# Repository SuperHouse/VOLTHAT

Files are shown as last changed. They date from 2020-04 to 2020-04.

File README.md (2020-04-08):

Voltage Regulator Hat for Raspberry Pi
=======================================
Designed by Nick Fryer and Jonathan Oxer

FEATURES
--------

Supply power via screw terminals, 2.1mm DC jack, or the PoE header on
Raspberry Pi 3 B+. Regulates down to 5V to supply the Raspberry Pi.

 * I2C header for OLED.
 * I2C-BREAKOUT header.
 * Prototyping area.

INSTALLATION
------------
The design is saved as an EAGLE project. EAGLE PCB design software is
available from www.cadsoftusa.com free for non-commercial use. To use
this project download it and place the directory containing these files
into the "eagle" directory on your computer. Then open EAGLE and
navigate to the project.

DISTRIBUTION
------------
The specific terms of distribution of this project are governed by the
license referenced below.

LICENSE
-------
Licensed under the TAPR Open Hardware License (www.tapr.org/OHL).
The "license" folder within this repository also contains a copy of
this license in plain text format.

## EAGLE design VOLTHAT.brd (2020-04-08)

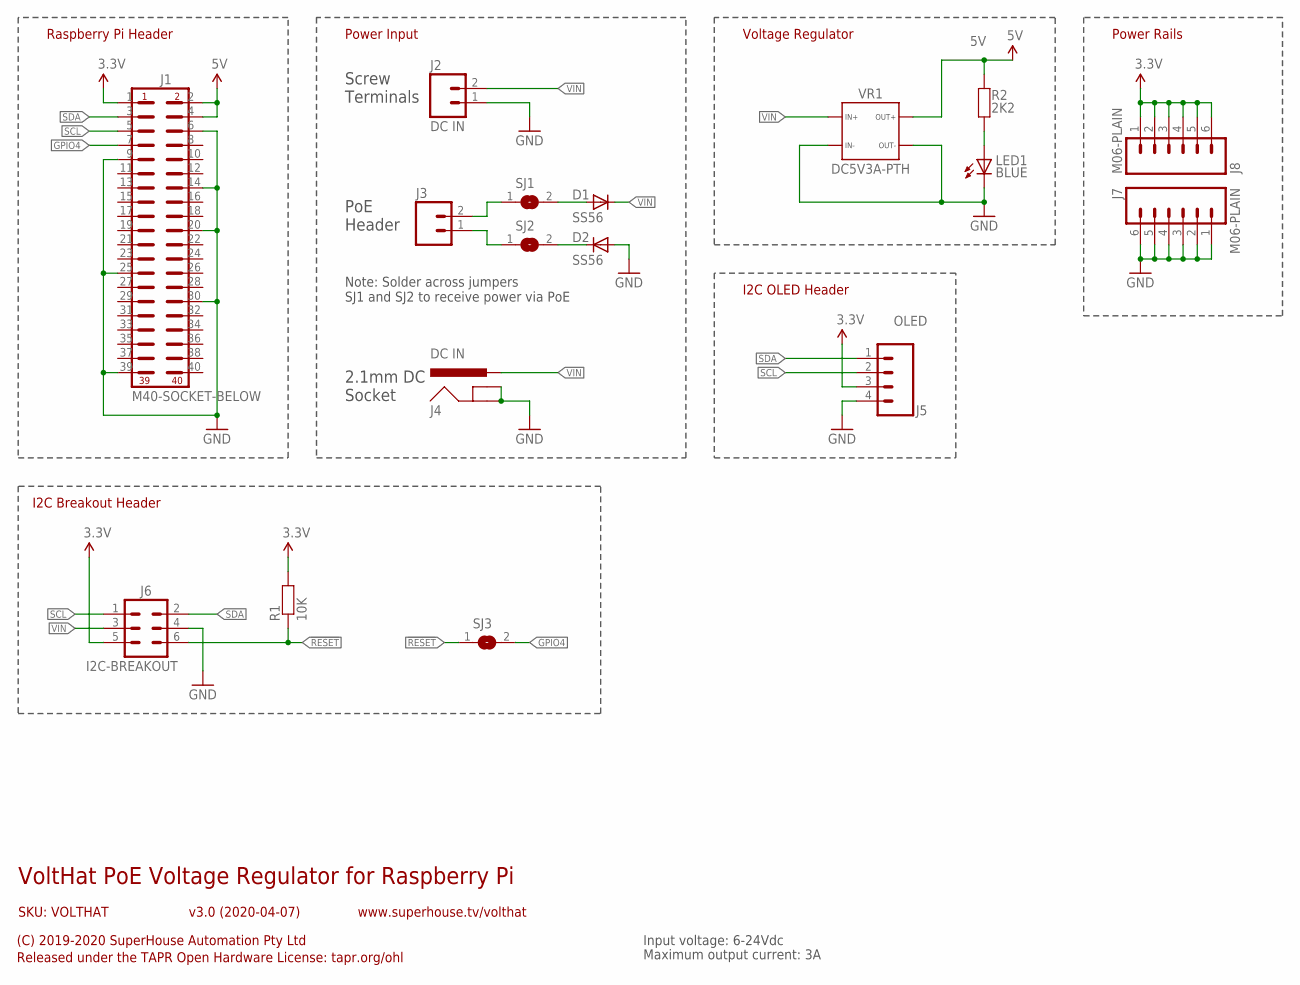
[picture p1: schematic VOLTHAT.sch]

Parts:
D1, D2: SS56; SMA-DIODE
J1: M40-SOCKET-BELOW; 2X20-S-BELOW
J2: DC IN; SCREWTERMINAL-3.5MM-2
J3: M02-SOCKET-BELOW; 1X02-S-BELOW
J4: DC IN; POWER_JACK_SLOTS
J5: OLED; 1X04
J6: I2C-BREAKOUT; 2X03-SHROUDED
J7, J8: M06-PLAIN; 1X06
LED1: BLUE; LED-0603
R1: 10K; R0603
R2: 2K2; R0603
SJ1, SJ2, SJ3: SJ-NORMAL; SJ
VR1: DC5V3A-PTH

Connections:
3.3V: J1.1, J5.3, J6.5, J8.1, J8.2, J8.3, J8.4, J8.5, J8.6, R1.2
5V: J1.2, J1.4, R2.1, VR1.3A (3), VR1.3B (3)
!RESET: J6.6, R1.1, SJ3.1
GND: D2.A, J1.6, J1.9, J1.14, J1.20, J1.25, J1.30, J1.39, J2.1, J4.GND, J4.GNDBREAK, J5.4, J6.4, J7.1, J7.2, J7.3, J7.4, J7.5, J7.6, LED1.C, VR1.1A (1), VR1.1B (1), VR1.4A (4), VR1.4B (4)
GPIO4: J1.7, SJ3.2
unnamed: J3.1, SJ2.1
unnamed: J3.2, SJ1.1
unnamed: D1.A, SJ1.2
unnamed: D2.C, SJ2.2
unnamed: LED1.A, R2.2
SCL: J1.5, J5.2, J6.1
SDA: J1.3, J5.1, J6.2
VIN: D1.C, J2.2, J4.PWR, J6.3, VR1.2A (2), VR1.2B (2)

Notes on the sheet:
VoltHat PoE Voltage Regulator for Raspberry Pi
v3.0 (2020-04-07)
(C) 2019-2020 SuperHouse Automation Pty Ltd
Released under the TAPR Open Hardware License: tapr.org/ohl
www.superhouse.tv/volthat
SKU: VOLTHAT
Raspberry Pi Header
Input voltage: 6-24Vdc
Maximum output current: 3A
Screw Terminals
PoE Header
2.1mm DC Socket
Power Input
I2C OLED Header
Power Rails
I2C Breakout Header
Voltage Regulator
Note: Solder across jumpers SJ1 and SJ2 to receive power via PoE

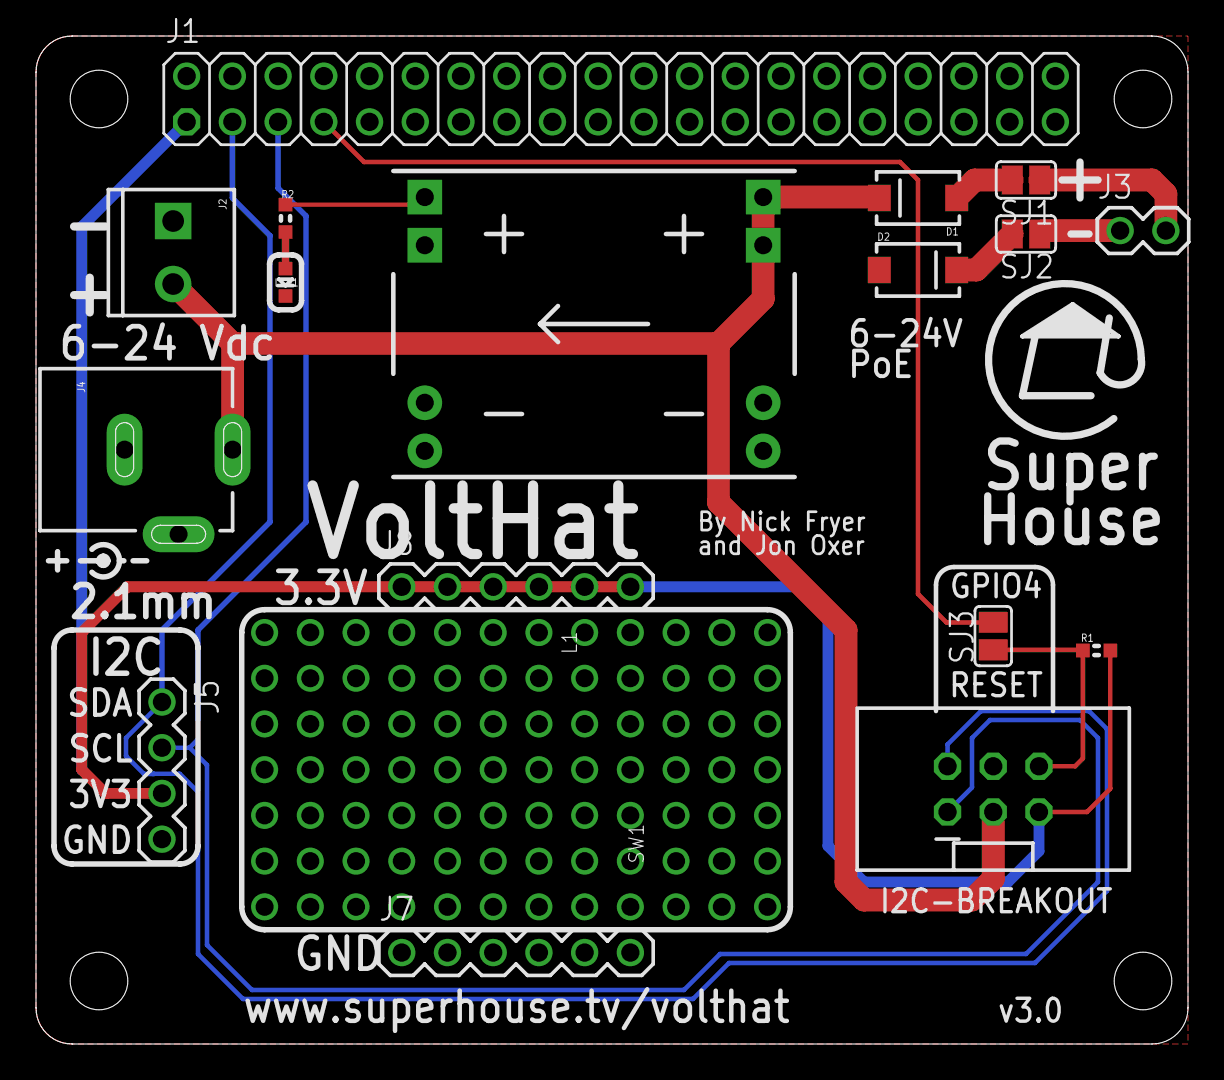
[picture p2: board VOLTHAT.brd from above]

Board: 2 copper layers, 64.0 x 56.0 mm, 17 parts (0 on the bottom side), 13 nets.

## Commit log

2019-05-10 Initial project import
    [ANTBRAIN.brd, ANTBRAIN.sch, VOLTHAT.brd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]
2019-05-15 Added header to take power from PoE on Raspberry Pi 3 B+
    [VOLTHAT.brd, VOLTHAT.sch]
2019-05-23 Major routing for v1.0 release
    [VOLTHAT.brd, VOLTHAT.sch]
2019-09-14 Major rework with 3A regulator module for v2.0 release
    [VOLTHAT.brd, VOLTHAT.sch]
2020-04-08 Added I2C-BREAKOUT header for v3.0 release
    [VOLTHAT.brd, VOLTHAT.sch]

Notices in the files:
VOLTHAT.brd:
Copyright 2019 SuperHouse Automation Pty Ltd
